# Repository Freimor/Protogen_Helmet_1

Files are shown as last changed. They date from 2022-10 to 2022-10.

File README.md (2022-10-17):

## Protogen Helmet for Wolfy

My first try to make protogen helmet. This design referenced to Kaiborg Studios LED helmet, but only conceptually. Overall design - 3d model of helmet, visor vacuum forming, PCB design - completely new. 




*what PCB contained, other electronics used*





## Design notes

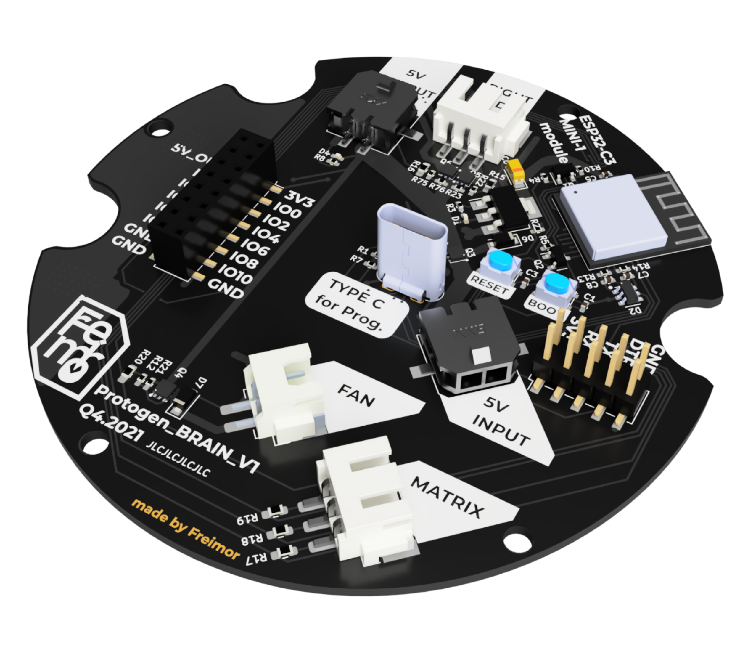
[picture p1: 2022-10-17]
Renders/Protohead_wolfy_4.png

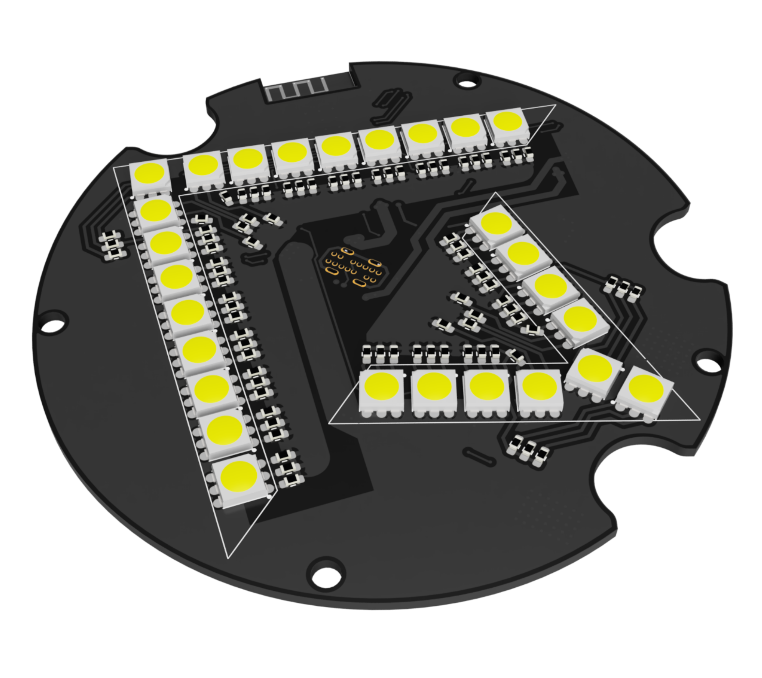
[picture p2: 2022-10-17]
Renders/Protohead_wolfy_3.PNG

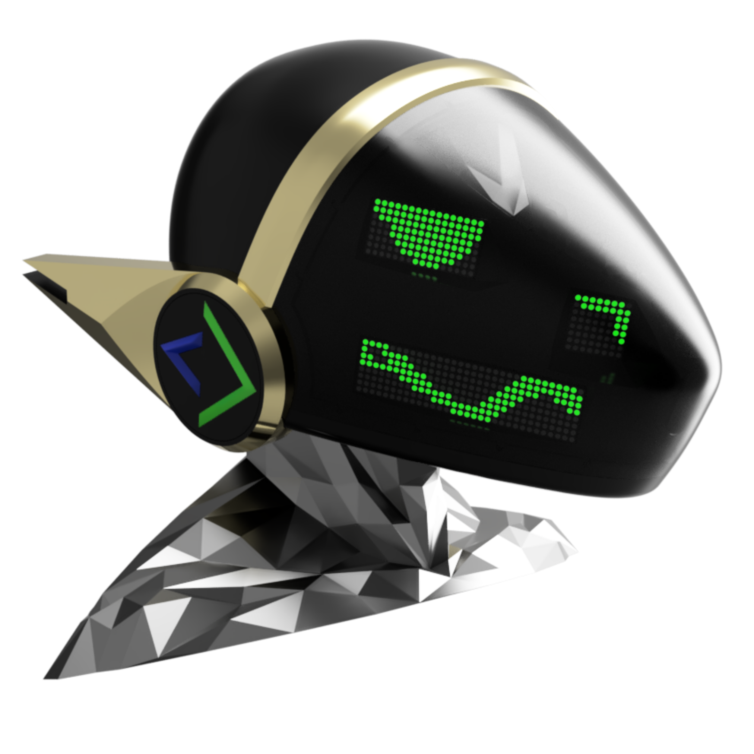
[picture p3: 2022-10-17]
Renders/Protohead_wolfy_6.png

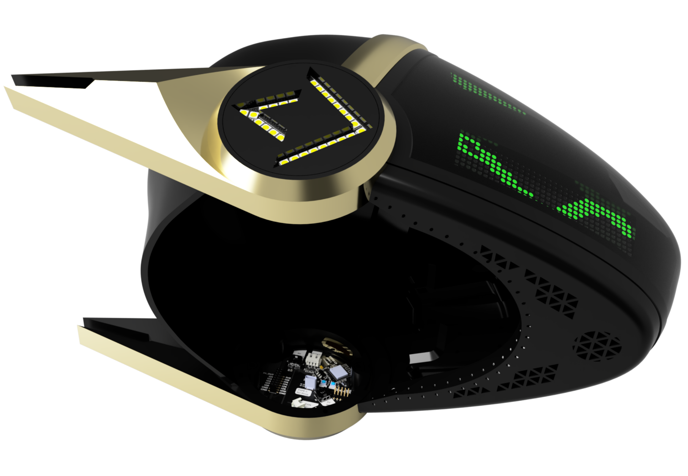
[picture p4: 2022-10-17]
Renders/Protohead_wolfy_2.png

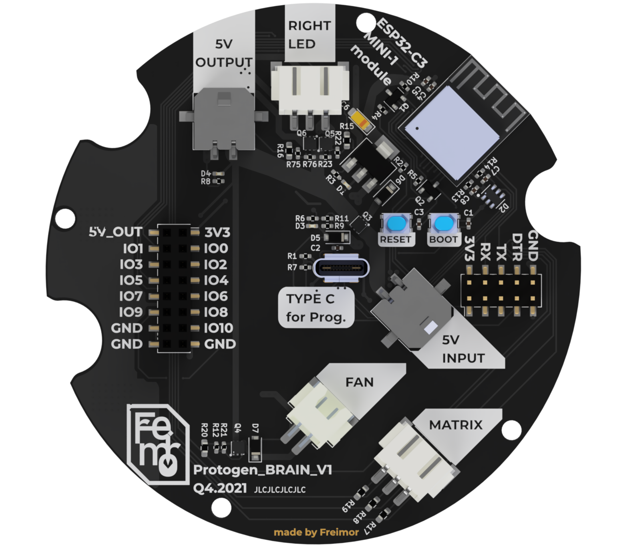
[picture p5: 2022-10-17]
Renders/Protohead_wolfy_5.png

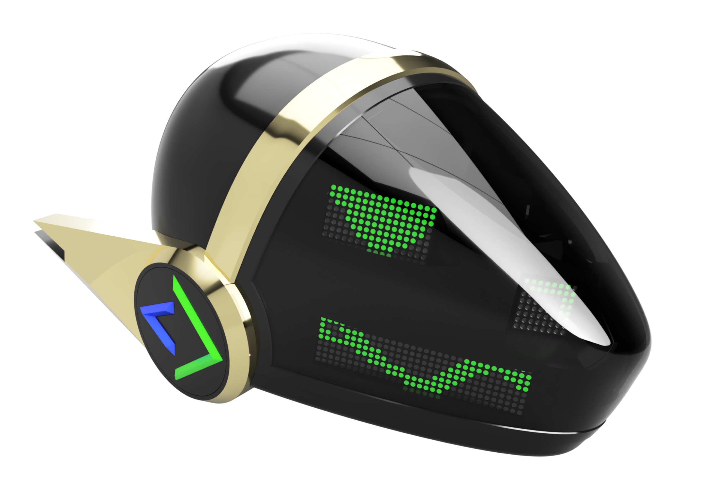
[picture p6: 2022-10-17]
Renders/Protohead_wolfy_1.png

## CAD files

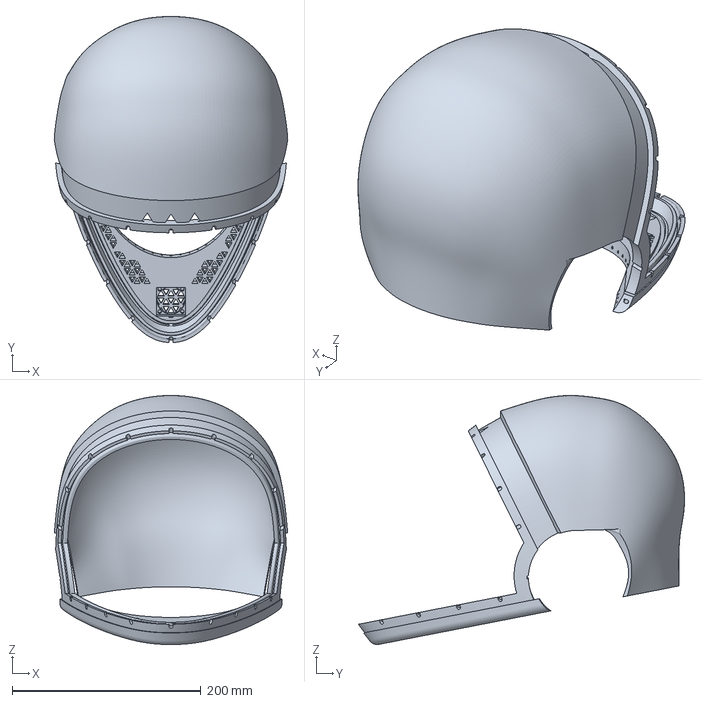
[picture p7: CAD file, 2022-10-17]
3d_models/helmet_main(PETG).3mf
247.2 x 345.1 x 263.6 mm

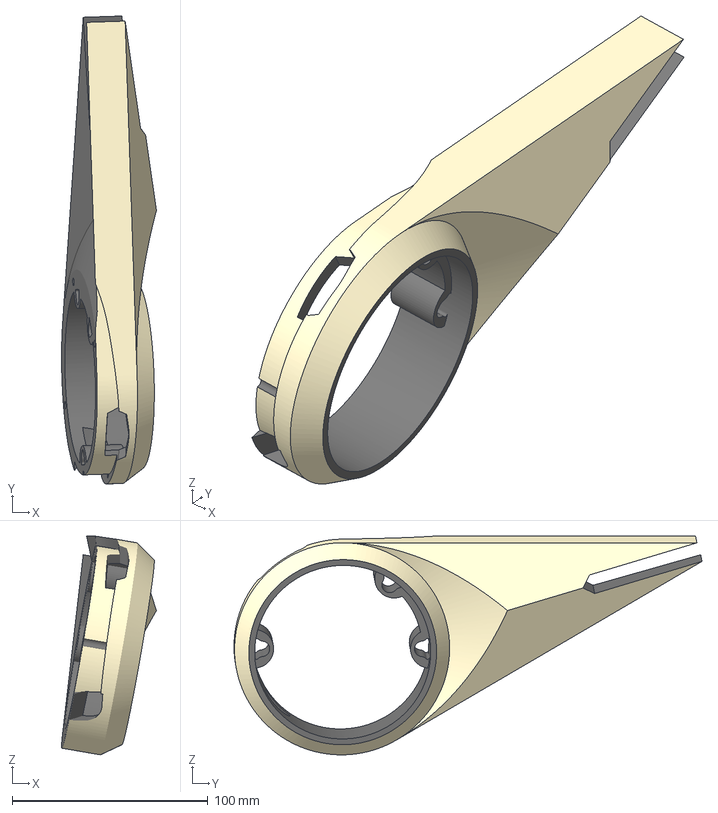
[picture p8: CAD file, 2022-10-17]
3d_models/ear_left_main(PETG).3mf
48.5 x 239.2 x 111.8 mm

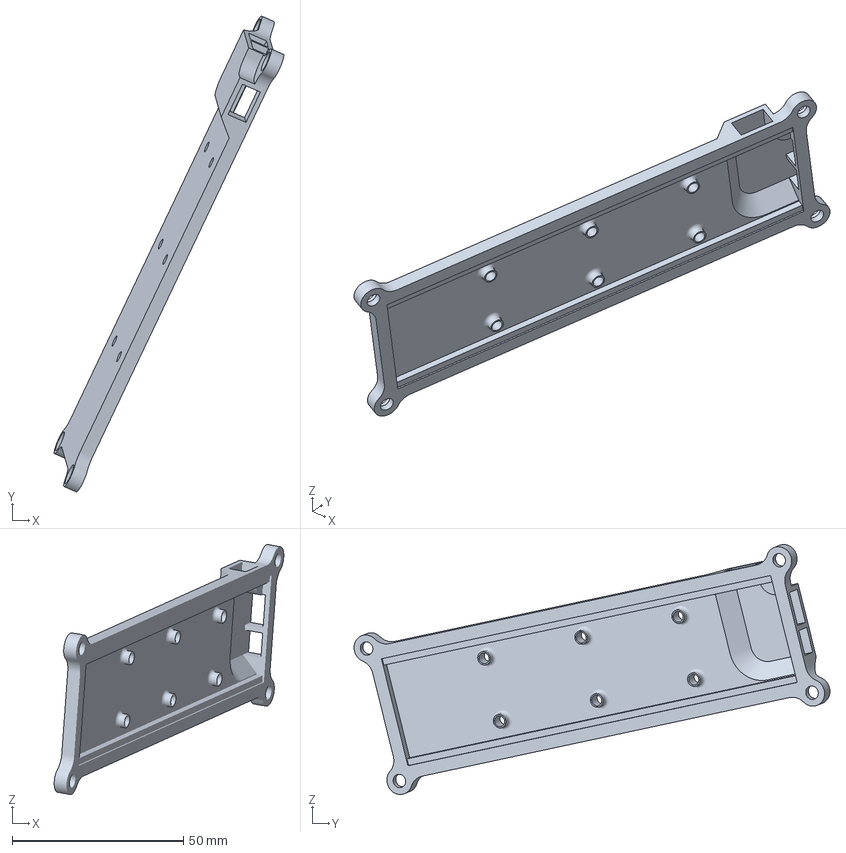
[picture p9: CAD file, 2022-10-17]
3d_models/visor_board_capfor4xmatrix_left.3mf
67.1 x 139.1 x 73.1 mm

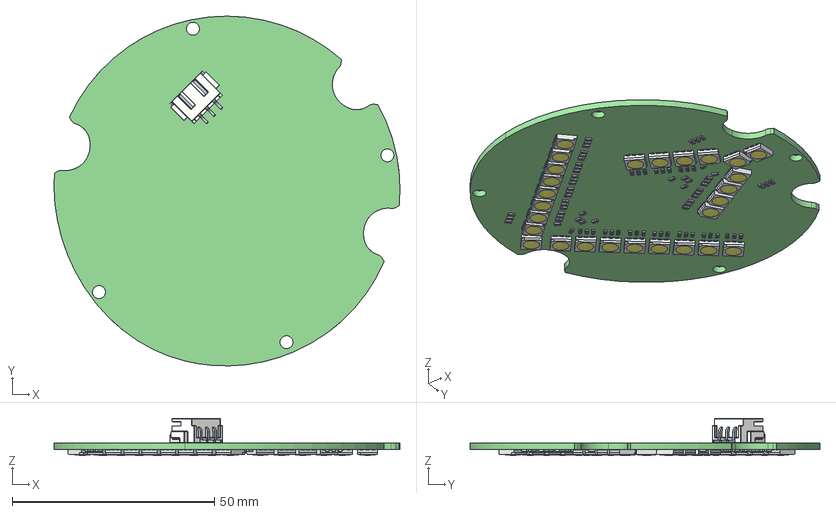
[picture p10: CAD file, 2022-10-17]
KiCad/Protogen_PCB_right.step
85.6 x 86.5 x 9.19 mm
Protogen_PCB_right PCB

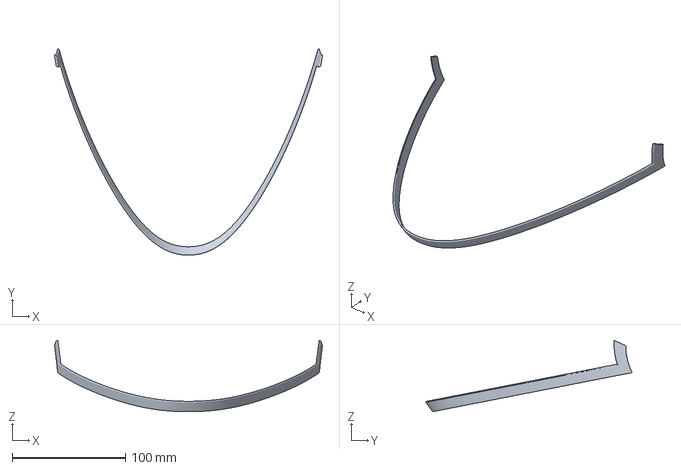
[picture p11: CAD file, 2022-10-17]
3d_models/visor_shell_2.3mf
236.8 x 182.3 x 63.0 mm

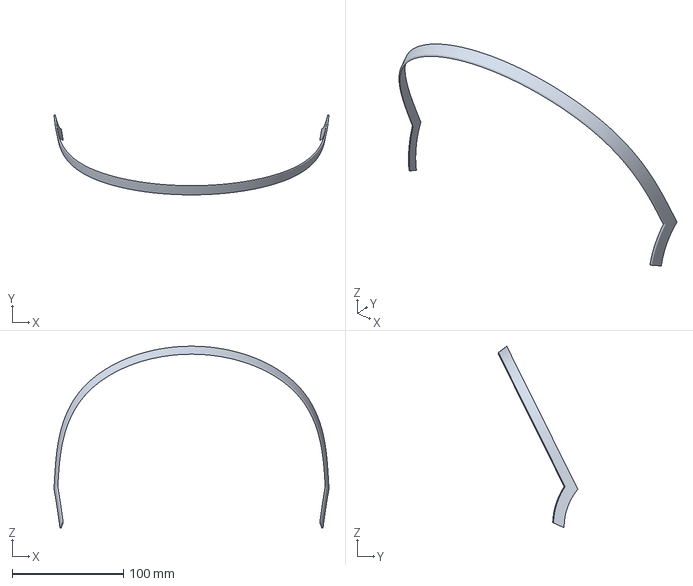
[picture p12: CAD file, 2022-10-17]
3d_models/visor_shell_1.3mf
247.5 x 71.8 x 163.4 mm

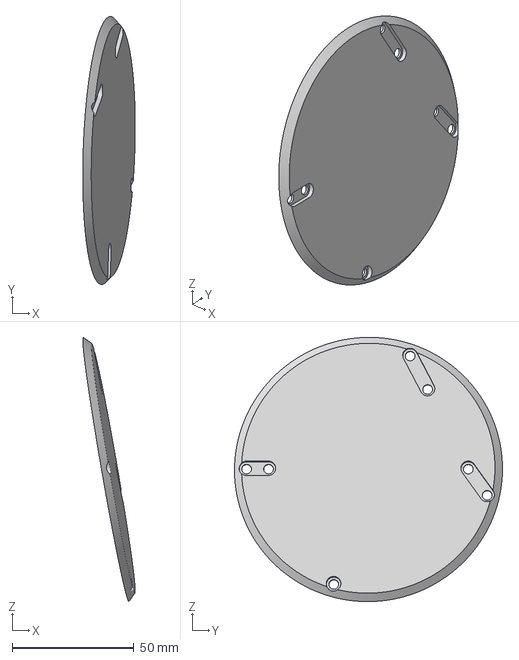
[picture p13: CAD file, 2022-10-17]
3d_models/ear_right_plate(PETG).3mf
21.5 x 109.9 x 108.4 mm

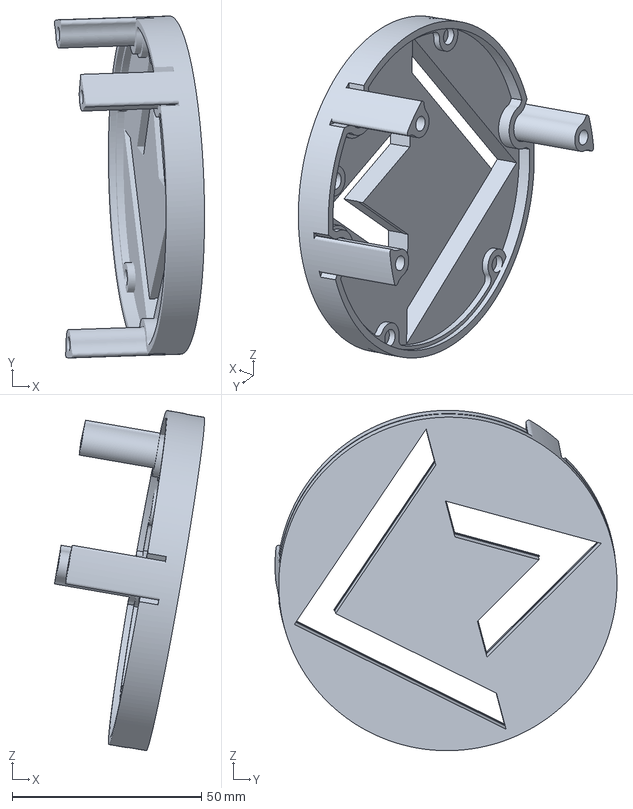
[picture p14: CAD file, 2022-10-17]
3d_models/ear_left_pcb_holder(PETG).3mf
39.7 x 90.4 x 90.0 mm

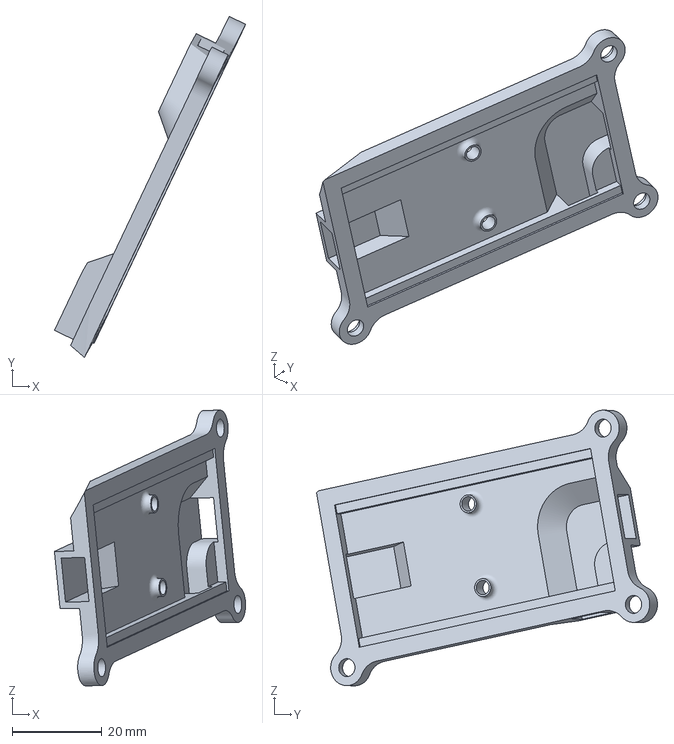
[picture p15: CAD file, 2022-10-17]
3d_models/visor_board_capfor2xmatrix_left.3mf
42.5 x 75.9 x 61.3 mm

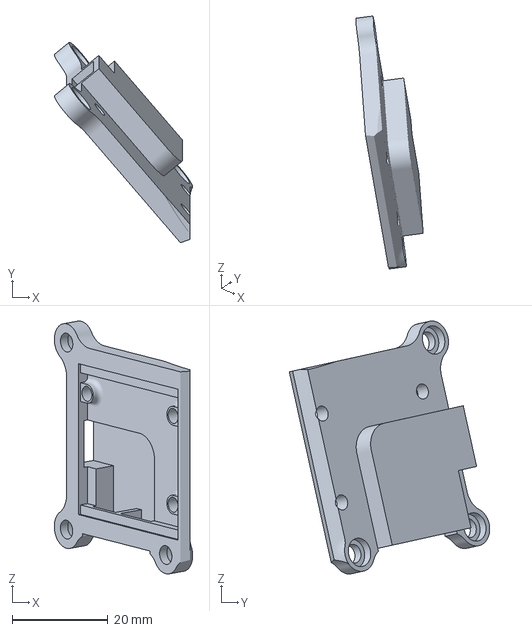
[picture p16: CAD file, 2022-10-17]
3d_models/visor_board_capfor1xmatrix_right.3mf
28.9 x 41.9 x 52.9 mm

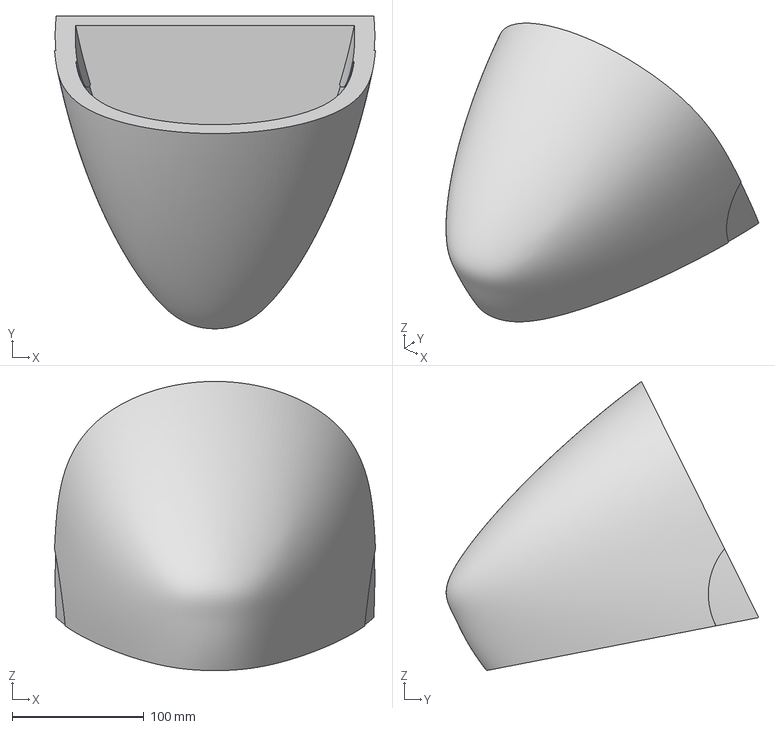
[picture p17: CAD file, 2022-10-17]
3d_models/visor_matrix_for_vacuumForming(PETGorABS).3mf
244.0 x 237.7 x 219.8 mm

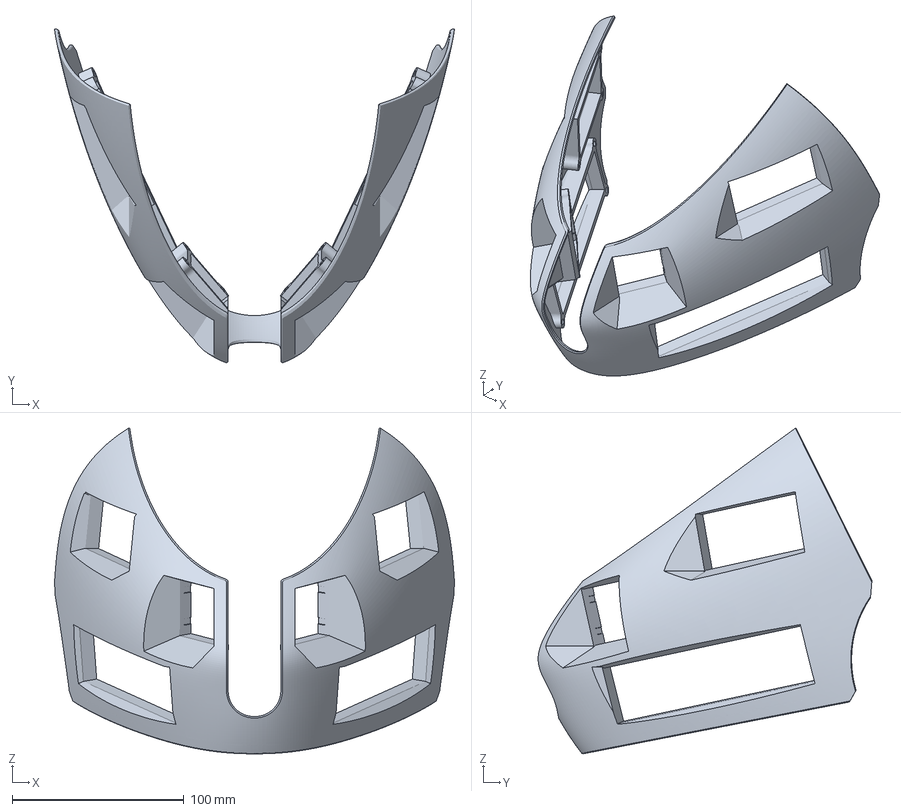
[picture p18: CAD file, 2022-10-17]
3d_models/visor_board_for_led.3mf
232.7 x 194.2 x 189.5 mm

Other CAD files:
3d_models/ear_right_main(PETG).3mf
3d_models/visor_board_capfor4xmatrix_right.3mf
3d_models/ear_right_pcb_holder(PETG).3mf
3d_models/visor_board_capfor2xmatrix_right.3mf
3d_models/ear_left_plate(PETG).3mf
3d_models/visor_board_capfor1xmatrix_left.3mf
3d_models/helmet_rim(PETG).3mf

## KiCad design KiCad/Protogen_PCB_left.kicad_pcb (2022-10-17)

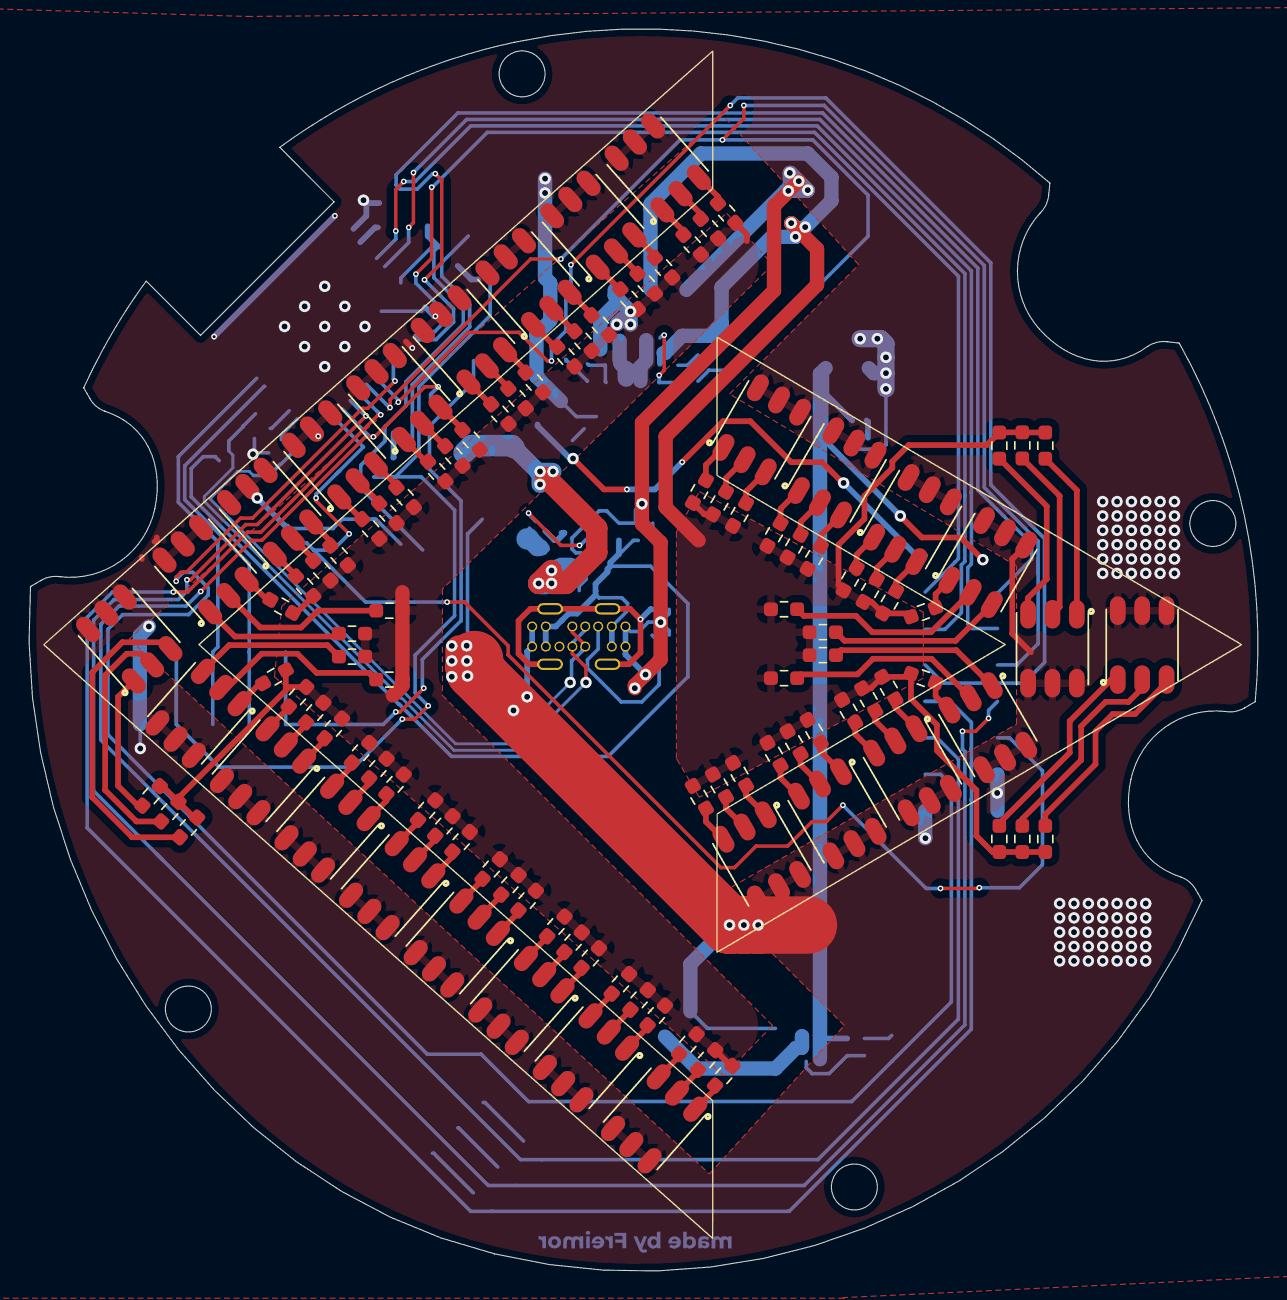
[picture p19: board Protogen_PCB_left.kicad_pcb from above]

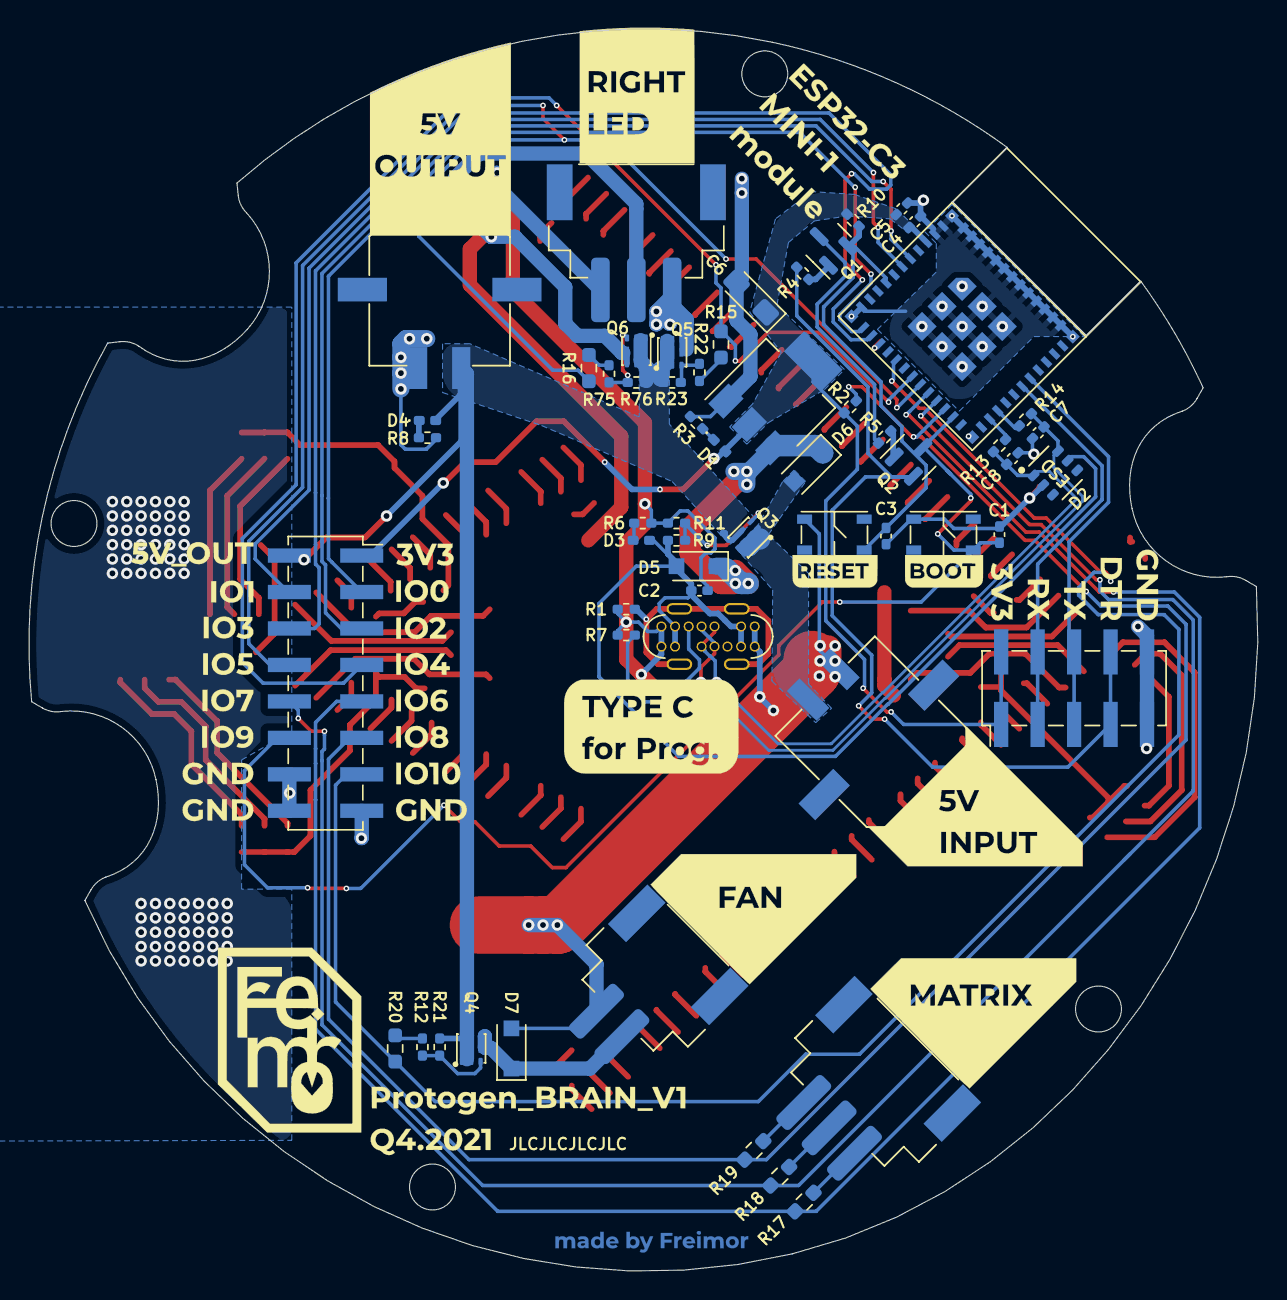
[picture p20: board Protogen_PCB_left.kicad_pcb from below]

Board: 2 copper layers, 85.6 x 86.5 mm, 168 parts (58 on the bottom side), 127 nets.

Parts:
BOOT: PTS810SJ; SW_SMD_C&K_(PTS810SJ)
C1, C3, C5: 100nF; C_0402_1005Metric_Pad0.74x0.62mm_HandSolder
C2, C4: 10uF; C_0402_1005Metric_Pad0.74x0.62mm_HandSolder
C6: 22uF; CP_EIA-3216-18_Kemet-A_Pad1.58x1.35mm_HandSolder
C7, C8: 22pF; C_0402_1005Metric_Pad0.74x0.62mm_HandSolder
D1, D3, D4: LED; LED_0402_1005Metric_Pad0.77x0.64mm_HandSolder
D2: IP4220CZ6
D5, D6, D7: D; D_SOD-123F
D8, D9, D10, D11, D12, D13, D14, D15, D16, D17, D18, D19, D20, D21, D22, D23, D24: LED_GREEN; LED_5050_HL-AF-5060
D25, D26, D27, D28, D29, D30, D31, D32, D33, D34: LED_BLUE; LED_5050_HL-AF-5060
J1: USB_C_Receptacle_USB2.0; USB_C_Receptable_918-418K2022Y40000
J2: INPUT_POWER; Conn_XKB_MX3_X3025WRS-02
J3: Conn_01x16_Male; PinSocket_2x08_P2.54mm_Vertical_SMD
J4: CONN_SIDE_LED; Conn_XKB_XH2.54_3pin_(X8821WRS-03)
J5: OUTPUT_POWER; Conn_XKB_MX3_X3025WRS-02
J6: UART; PinHeader_2x05_P2.54mm_Vertical_SMD
J7: CONN_MATRIX; Conn_XKB_XH2.54_3pin_(X8821WRS-03)
J8: FAN; Conn_XKB_XH2.54_2pin_(X8821WRS-02)
Q1, Q2: L8050; SOT-23
Q3, Q4, Q5, Q6: HSCB2307(P_Mosfet_8A_20V); HSCB2307
R1: 1M; R_0402_1005Metric_Pad0.72x0.64mm_HandSolder
R2, R4, R5, R10, R11, R21, R23, R76: 10k; R_0402_1005Metric_Pad0.72x0.64mm_HandSolder
R3, R6, R8, R9, R12, R22, R75: 1k; R_0402_1005Metric_Pad0.72x0.64mm_HandSolder
R7: 5k1; R_0402_1005Metric_Pad0.72x0.64mm_HandSolder
R13, R14: 22; R_0402_1005Metric_Pad0.72x0.64mm_HandSolder
R15, R16, R17, R18, R19, R20: 0; R_0603_1608Metric_Pad0.98x0.95mm_HandSolder
R24, R25, R26, R27, R28, R29, R30, R31, R32, R33, R34, R35, R36, R37, R38, R39, R40, R41, R42, R43, R44, R45, R46, R47, R48, R49, R50, R51, R52, R53, R54, R55, R56, R57, R58, R59, R60, R61, R62, R63, R64, R65, R66, R67, R68, R69, R70, R71, R72, R73, R74, R77, R78, R79, R80, R81, R82, R83, R84, R85, R86, R87, R88, R89, R90, R91, R92, R93, R94, R95, R96, R97, R98, R99, R100, R101, R102, R103, R104, R105, R106: 300; R_0603_1608Metric_Pad0.98x0.95mm_HandSolder
RESET: PTS810SJ; SW_SMD_C&K_(PTS810SJ)
Ref**: Val**; Headphone_right_silk
Ref_silk: Val**; Wolfy_headphone_left_PCB
U1: AMS1117-3.3; SOT-223-3_TabPin2
U2: ESP32-C3-MINI-1-N4; ESP32-C3-MINI-1

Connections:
3v3: C4.1, C5.1, C6.1, D1.2, J3.1, J6.1, J6.2, R2.1, R10.1, U1.2, U2.3
5v_INPUT: D6.2, J2.1, Q3.1, Q3.2, Q3.5, Q3.6, Q3.8
5v_OUTPUT: D4.2, J3.2, J5.1, Q3.4, Q3.7, Q4.1, Q4.2, Q4.5, Q4.6, Q4.8, Q5.1, Q5.2, Q5.5, Q5.6, Q5.8, Q6.1, Q6.2, Q6.5, Q6.6, Q6.8, R21.1, R23.1, R76.1
BLUE_LED_ANODE: J4.2, Q6.4, Q6.7, R77.2, R78.2, R79.2, R80.2, R81.2, R82.2, R83.2, R84.2, R85.2, R86.2, R87.2, R88.2, R89.2, R90.2, R91.2, R92.2, R93.2, R94.2, R95.2, R96.2, R97.2, R98.2, R99.2, R100.2, R101.2, R102.2, R103.2, R104.2, R105.2, R106.2
D+: C7.1, D2.6, J1.A6, J1.B6, R14.1
D-: C8.1, D2.1, J1.A7, J1.B7, R13.1
DTR: J6.7, J6.8, Q2.2, R4.2
EN: C3.1, Q1.2, R10.2, RESET.4, U2.8
GND: BOOT.1, C1.2, C2.2, C3.2, C4.2, C5.2, C6.2, C7.2, C8.2, D2.2, D7.2, D8.4, D8.5, D8.6, D9.4, D9.5, D9.6, D10.4, D10.5, D10.6, D11.4, D11.5, D11.6, D12.4, D12.5, D12.6, D13.4, D13.5, D13.6, D14.4, D14.5, D14.6, D15.4, D15.5, D15.6, D16.4, D16.5, D16.6, D17.4, D17.5, D17.6, D18.4, D18.5, D18.6, D19.4, D19.5, D19.6, D20.4, D20.5, D20.6, D21.4, D21.5, D21.6, D22.4, D22.5, D22.6, D23.4, D23.5, D23.6, D24.4, D24.5, D24.6, D25.4, D25.5, D25.6, D26.4, D26.5, D26.6, D27.4, D27.5, D27.6, D28.4, D28.5, D28.6, D29.4, D29.5, D29.6, D30.4, D30.5, D30.6, D31.4, D31.5, D31.6, D32.4, D32.5, D32.6, D33.4, D33.5, D33.6, D34.4, D34.5, D34.6, J1.A1, J2.2, J3.14, J3.15, J3.16, J4.3, J5.2, J6.9, J6.10, J8.2, R1.2, R3.2, R6.2, R7.2, R8.2, R11.2, RESET.1, U1.1, U2.1, U2.2, U2.11, U2.14, U2.36, U2.37, U2.38, U2.39, U2.40, U2.41, U2.42, U2.43, U2.44, U2.45, U2.46, U2.47, U2.48, U2.49, U2.50, U2.51, U2.52, U2.53
GREEN_LED_ANODE: J4.1, Q5.4, Q5.7, R24.2, R25.2, R26.2, R27.2, R28.2, R29.2, R30.2, R31.2, R32.2, R33.2, R34.2, R35.2, R36.2, R37.2, R38.2, R39.2, R40.2, R41.2, R42.2, R43.2, R44.2, R45.2, R46.2, R47.2, R48.2, R49.2, R50.2, R51.2, R52.2, R53.2, R54.2, R55.2, R56.2, R57.2, R58.2, R59.2, R60.2, R61.2, R62.2, R63.2, R64.2, R65.2, R66.2, R67.2, R68.2, R69.2, R70.2, R71.2, R72.2, R73.2, R74.2
IO0: J3.3, U2.12
IO1: J3.4, U2.13
IO2: J3.5, U2.5
IO3: J3.6, U2.6
IO4: J3.7, R15.2, U2.18
IO4_GREEN_LED: R15.1, R22.2
IO5: J3.8, R16.2, U2.19
IO5_BLUE_LED: R16.1, R75.2
IO6: J3.9, R17.2, U2.20
IO6_Matrix_SPI_DATA: J7.1, R17.1
IO7: J3.10, R18.2, U2.21
IO7_Matrix_SPI_SCK: J7.2, R18.1
IO8: J3.11, R2.2, R19.2, U2.22
IO8_Matrix_SPI_CS: J7.3, R19.1
IO9: BOOT.4, C1.1, J3.12, Q2.3, U2.23
IO10: J3.13, R20.2, U2.16
IO10_FAN: R12.2, R20.1
unnamed: D1.1, R3.1
unnamed: D3.1, R6.1
unnamed: D4.1, R8.1
unnamed: D5.1, D6.1, U1.3
unnamed: D7.1, J8.1, Q4.4, Q4.7
unnamed: D8.1, R24.1
unnamed: D8.2, R25.1
unnamed: D8.3, R26.1
unnamed: D9.1, R27.1
unnamed: D9.2, R28.1
unnamed: D9.3, R29.1
unnamed: D10.1, R30.1
unnamed: D10.2, R31.1
unnamed: D10.3, R32.1
unnamed: D11.1, R33.1
unnamed: D11.2, R34.1
unnamed: D11.3, R35.1
unnamed: D12.1, R36.1
unnamed: D12.2, R37.1
unnamed: D12.3, R38.1
unnamed: D13.1, R39.1
unnamed: D13.2, R40.1
unnamed: D13.3, R41.1
unnamed: D14.1, R42.1
unnamed: D14.2, R43.1
unnamed: D14.3, R44.1
unnamed: D15.1, R45.1
unnamed: D15.2, R46.1
unnamed: D15.3, R47.1
unnamed: D16.1, R48.1
unnamed: D16.2, R49.1
unnamed: D16.3, R50.1
unnamed: D17.1, R51.1
unnamed: D17.2, R52.1
unnamed: D17.3, R53.1
unnamed: D18.1, R54.1
unnamed: D18.2, R55.1
unnamed: D18.3, R56.1
unnamed: D19.1, R57.1
unnamed: D19.2, R58.1
unnamed: D19.3, R59.1
unnamed: D20.1, R60.1
unnamed: D20.2, R61.1
unnamed: D20.3, R62.1
unnamed: D21.1, R63.1
unnamed: D21.2, R64.1
unnamed: D21.3, R65.1
unnamed: D22.1, R66.1
unnamed: D22.2, R67.1
unnamed: D22.3, R68.1
unnamed: D23.1, R69.1
unnamed: D23.2, R70.1
unnamed: D23.3, R71.1
unnamed: D24.1, R72.1
unnamed: D24.2, R73.1
unnamed: D24.3, R74.1
unnamed: D25.1, R77.1
unnamed: D25.2, R78.1
unnamed: D25.3, R79.1
unnamed: D26.1, R80.1
unnamed: D26.2, R81.1
unnamed: D26.3, R82.1
unnamed: D27.1, R83.1
unnamed: D27.2, R84.1
unnamed: D27.3, R85.1
unnamed: D28.1, R86.1
unnamed: D28.2, R87.1
unnamed: D28.3, R88.1
unnamed: D29.1, R89.1
unnamed: D29.2, R90.1
unnamed: D29.3, R91.1
unnamed: D30.1, R92.1
unnamed: D30.2, R93.1
unnamed: D30.3, R94.1
unnamed: D31.1, R95.1
unnamed: D31.2, R96.1
unnamed: D31.3, R97.1
unnamed: D32.1, R98.1
unnamed: D32.2, R99.1
unnamed: D32.3, R100.1
unnamed: D33.1, R101.1
unnamed: D33.2, R102.1
unnamed: D33.3, R103.1
unnamed: D34.1, R104.1
unnamed: D34.2, R105.1
unnamed: D34.3, R106.1
unnamed: J1.A5, R7.1
unnamed: J1.S1, R1.1
unnamed: Q1.1, R4.1
unnamed: Q2.1, R5.1
unnamed: Q3.3, R9.1, R11.1
unnamed: Q4.3, R12.1, R21.2
unnamed: Q5.3, R22.1, R23.2
unnamed: Q6.3, R75.1, R76.2
unnamed: R13.2, U2.26
unnamed: R14.2, U2.27
RESET: Q1.3, R5.2
RX: J6.3, J6.4, U2.30
TX: J6.5, J6.6, U2.31
VBUS: C2.1, D2.5, D3.2, D5.2, J1.A4, R9.2
